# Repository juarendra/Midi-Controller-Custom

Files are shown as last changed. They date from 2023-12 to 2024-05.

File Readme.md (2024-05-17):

# MIDI CONTROLLER CUSTOM
This is MIDI CONTROLLER Combine with Macropad. Midi controller is for sending midi key to computer, ussually usage for remix musi on DAW Software. Macropad usage to sending macro key that register on QMK/VIA Firmware. there are 2 Microcontroller on this Project, All Microcontroller using Pro Micro and Connected with USB HUB inside Case. Macropad is installed QMK/VIA Firmware and Midi Controller is installed using Arduino Framework. For Button Midi Controller we use Arcade Button and there are 2 RGB LED on each Arcade Button and For Macropad we use MX Mechanical Switch with RGB on South Face.

For Case, we use 3D print that you can download on [this folder](https://github.com/juarendra/Midi-Controller-Custom/tree/main/HARDWARE/3DCASE). You can print this if you want to build this Project. For Firmware you can find in [this folder](https://github.com/juarendra/Midi-Controller-Custom/tree/main/Firmware).

## Spesification
- 2 x Atmega32u4 Pro Micro
- 1 x USB HUB minimal 2 Port
- 16 x Button Arcade with Transparant Frame + 2 RGB each Button
- 5 x Mechanical MX Switch and Keycaps + 1 RGB per key
- 5 x Hotswap Switch
- 1 x Encoder 
- 1 x USB Type B Female
- Macropad Compatible With VIA

for Connection from Pro Micro to all Button and RGB you can use Connector and skun, 

## Preview Hardware
<p align="center">
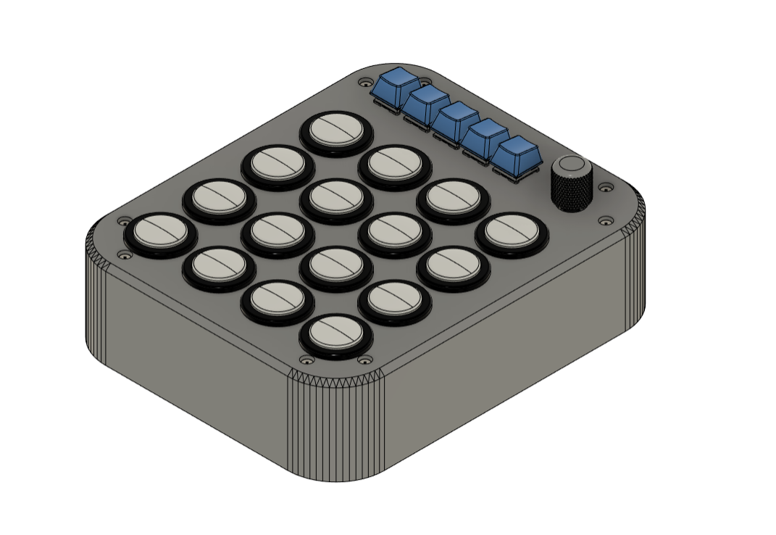
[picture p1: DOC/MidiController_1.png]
  
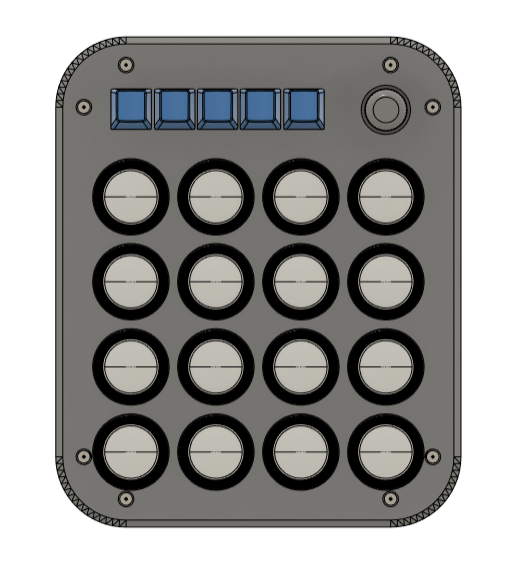
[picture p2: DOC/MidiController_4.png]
  
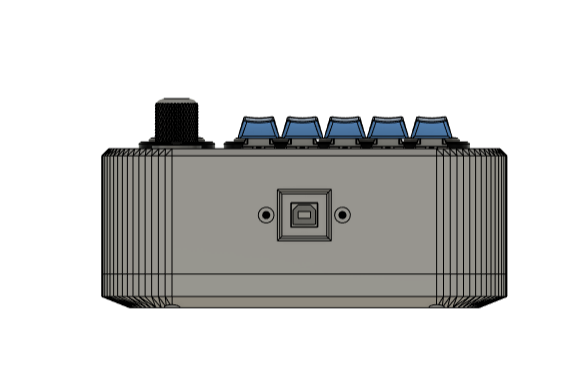
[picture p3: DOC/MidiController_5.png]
  
</p>

## Documentation Sensor V4
- [Dimension Sensor V4](https://github.com/juarendra/Midi-Controller-Custom/blob/main/HARDWARE/Dimension_MidiController.pdf)
- [JSON File For VIA](https://github.com/juarendra/Midi-Controller-Custom/blob/main/MidiController.json)

## BOM
| Item  | QTY |
| --- | --- |
| Arduino Pro Micor  | 2  |
| Arcade Button with transparant Frame 30mm | 16  |
| Switch Mechanical MX  | 5  |
| Keycaps Mechanical MX  | 5  |
| EC11 Rotary Encoder + Knob| 1  |
| Hotswap PCB Mechanical MX with LED RGB | 5  |
| RGB LED for Arcade Button | 32  |
| USB HUB minimal 2 Port | 1  |
| USB FEMALE type B | 1  |
| Wire and Skun | some  |

## FLASH FIRMWARE
- Flash QMK with QMK tollbox, the file you can find in [this link](https://github.com/juarendra/Midi-Controller-Custom/blob/main/Firmware/Macropad/25keys_cassette42_default.hex)
- Flash Midi Controller with arduino ,you need to install all library arduino, the file you can find in [this link](https://github.com/juarendra/Midi-Controller-Custom/blob/main/Firmware/MidiController/MidiController.ino)

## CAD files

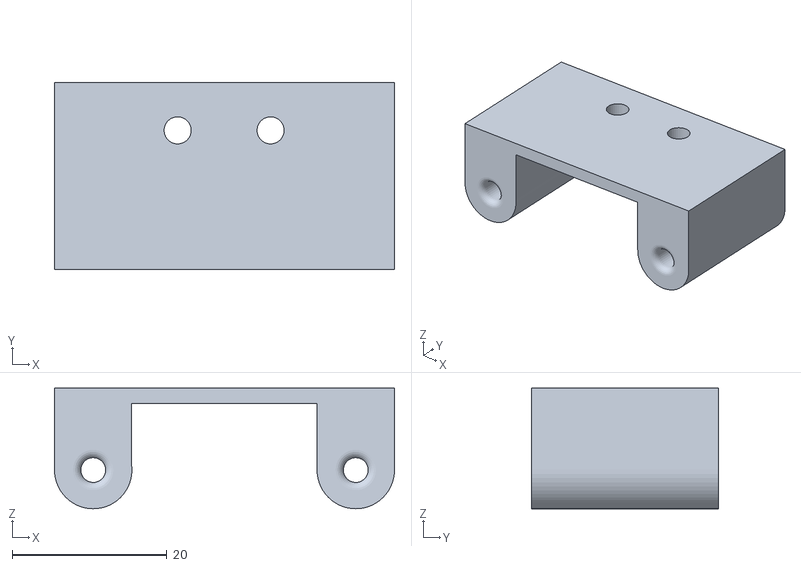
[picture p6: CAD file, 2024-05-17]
HARDWARE/3DCASE/USB_HOLDER_MidiController.stl
43.9 x 24.2 x 15.6

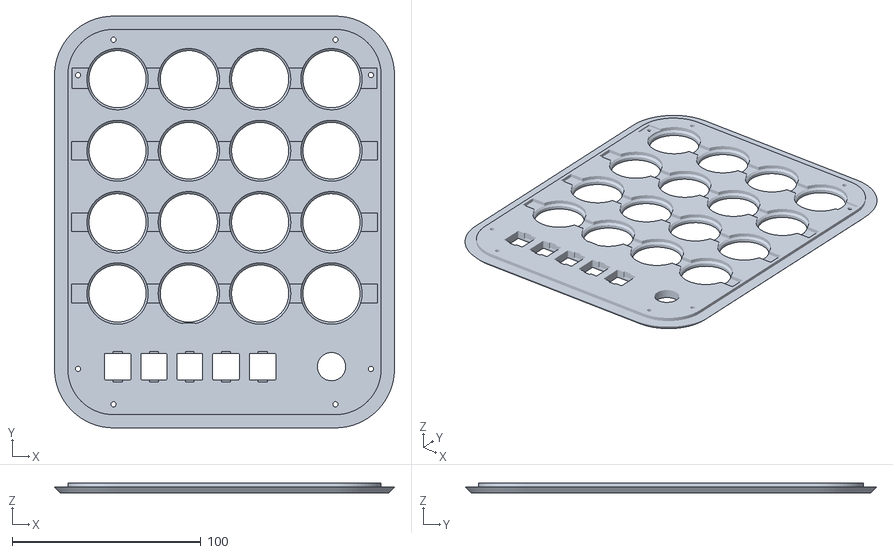
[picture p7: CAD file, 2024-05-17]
HARDWARE/3DCASE/TOP_MidiController.stl
180.0 x 218.0 x 5.27

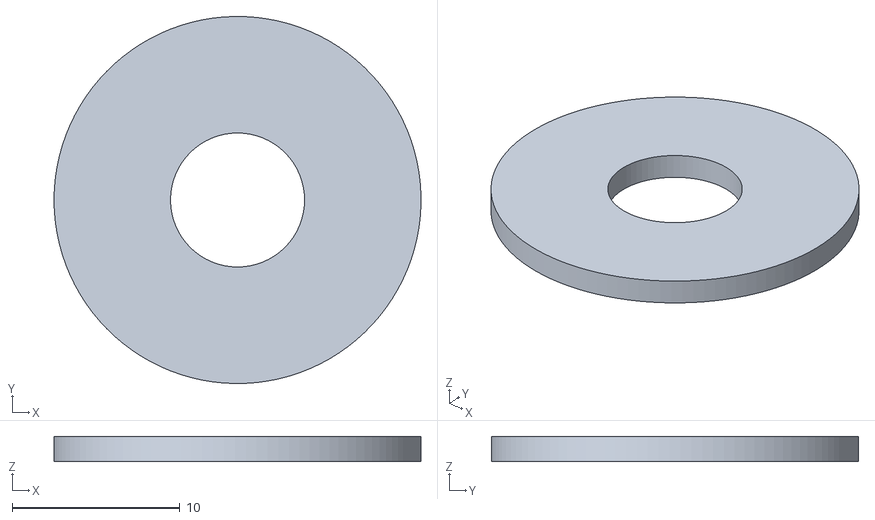
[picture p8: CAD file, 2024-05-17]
HARDWARE/3DCASE/ENCODER_BASE_MidiController.stl
21.9 x 21.9 x 1.50

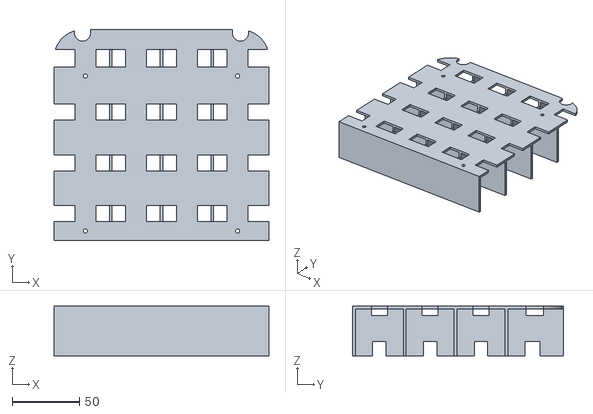
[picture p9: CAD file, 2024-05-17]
HARDWARE/3DCASE/LED_BRACKET_MidiController.stl
160.0 x 156.8 x 37.0

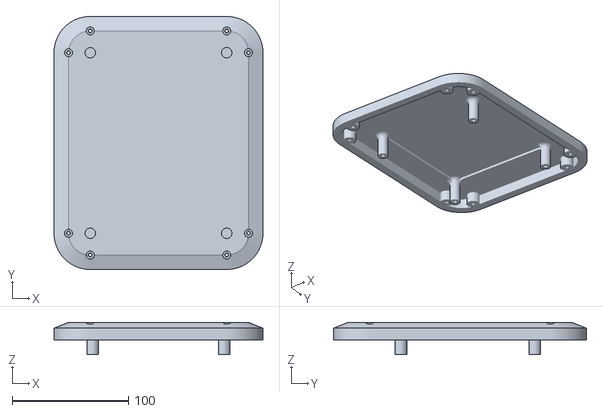
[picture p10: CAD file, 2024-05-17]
HARDWARE/3DCASE/BOTTOM_MidiController.stl
180.0 x 218.0 x 27.8

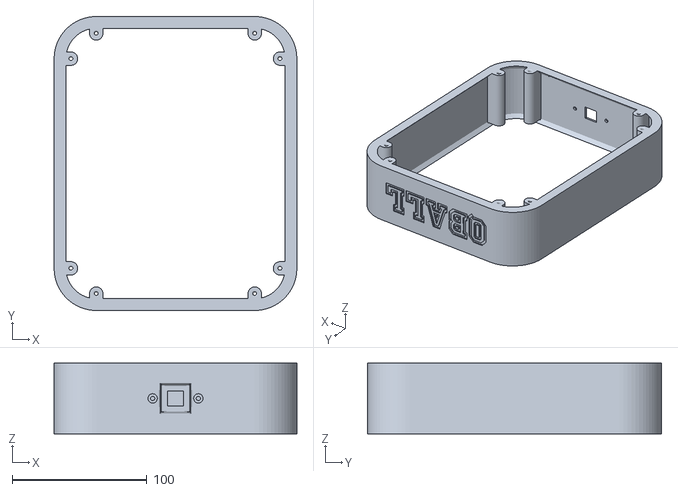
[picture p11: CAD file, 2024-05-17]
HARDWARE/3DCASE/MIDDLE_MidiController.stl
180.0 x 218.0 x 52.6

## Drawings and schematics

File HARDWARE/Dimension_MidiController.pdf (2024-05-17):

218 ¹⁸⁰ | 37.75 | 3.75 1.35 | 18.05 Ø7Ø25.5 | Ø34 | Ø9 Rubber Feet | Ø7 Baut M3 | Switch Knob Baut Arcade Button Ø7 Baut M3 USB Type B Female

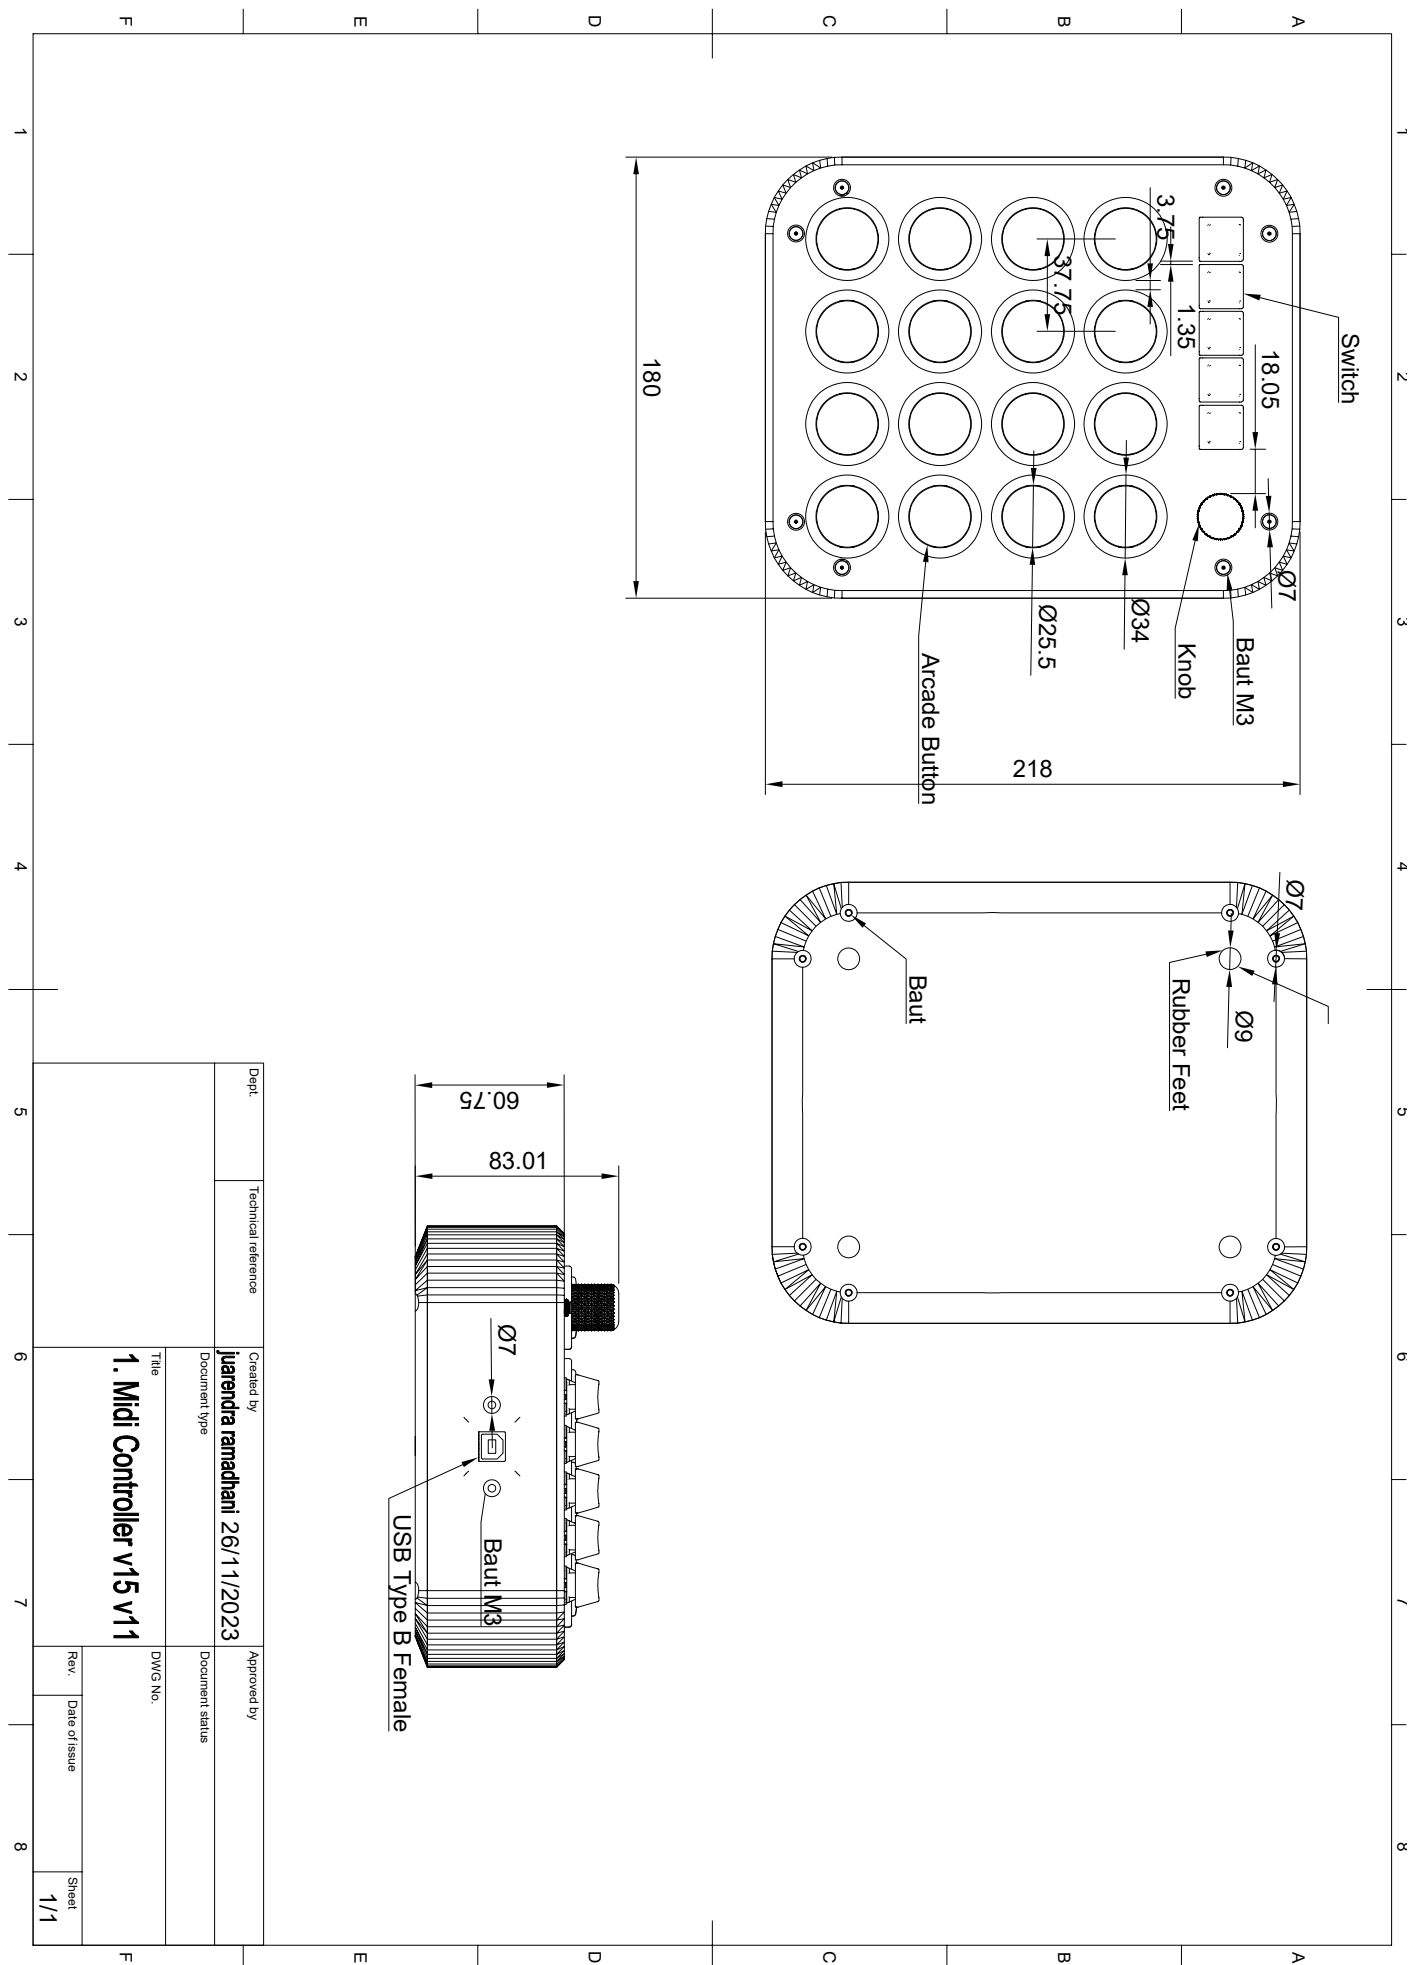
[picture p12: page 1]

1 A 2 3 4 5 6 7 8 1 2 3 4 5 6 7 8 FEDCB FEDCBA Dept. Technical reference Created by Approved by Title DWG No. Document type Document status Rev. Date of issue Sheet 26/11/2023 1/1

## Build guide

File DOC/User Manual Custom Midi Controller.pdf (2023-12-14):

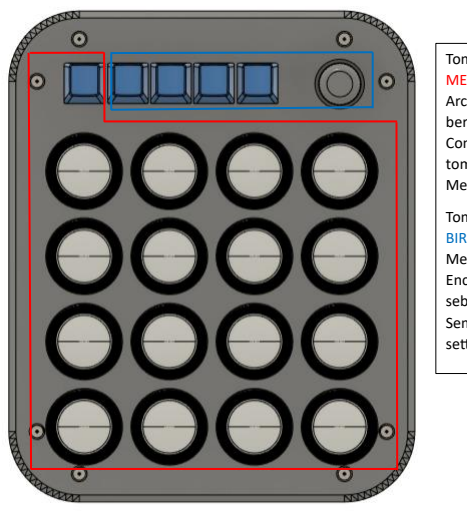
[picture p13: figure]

1. 16 Arcade Button
Berfungsi sebagai MIDI Controller yang mengirimkan signal note ke PC, Berikut merupakan maping dari note sesuai posisi button
48 | 49 | 50 | 51
44 | 45 | 46 | 47
40 | 41 | 42 | 43
36 | 37 | 38 | 39

Posisi ini menyesuaikan dengan posisi pads yang ada di aplikasi mpc beats

2. 1 Mechanical Button untuk menu
Berfungsi sebagai tombol untuk masuk ke menu yang ada di device. Ketika tombol ini di tekan dan ditahan maka akan memasuki mode menu., dan untuk memindahkan menu user perlu menekan tombol arcade sesuai dengan mapping menunya Tolong lihat video untuk lebih jelasnya.

Tombol didalam Kotak
MERAH : Terdiri dari 16
Arcade Button yang
berfungsi sebagai Midi
Controller dengan 1
tombol diatas untuk
Menu

Tombol didalam Kotak
BIRU : Terdiri dari 4
Mechanical Button dan 1
Encoder yang berfungsi
sebagai Macropad.
Semua key dapat di
setting dengan apps VIA

Berikut merupakan mapping menu sesuai posisi arcade button

Merubah warna pada Channel 3 ketika tombol ditekan | Merubah warna pada Channel 4 ketika tombol ditekan | Merubah warna pada Channel 5 ketika tombol ditekan | Merubah Brightness LED tombol
Merubah warna pada Channel 4 ketika tombol tidak ditekan | Merubah warna pada Channel 5 ketika tombol tidak ditekan | Merubah warna pada Channel 1 ketika tombol ditekan | Merubah warna pada Channel 2 ketika tombol ditekan
Midi Controller Channel 5 | Merubah warna pada Channel 1 ketika tombol tidak ditekan | Merubah warna pada Channel 2 ketika tombol tidak ditekan | Merubah warna pada Channel 3 ketika tombol tidak ditekan
Midi Controller Channel 1 | Midi Controller Channel 2 | Midi Controller Channel 3 | Midi Controller Channel 4

### 3. LED INDICATOR

Anda dapat mengetahui anda berada di menu apa dengan meilhat 5 LED yang ada di bawah 5 Mechanical Button. Berikut merupakan Contoh dari indicator lednya
1. Anda berada di Midi Controller Channel 1

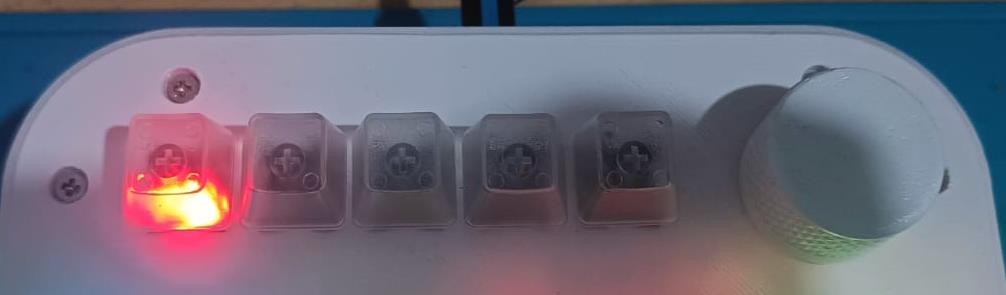
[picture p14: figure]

2. Anda berada di Midi Conntroller Channel 5
3. Anda berada di Setting warna Ketika tombol tidak ditekan

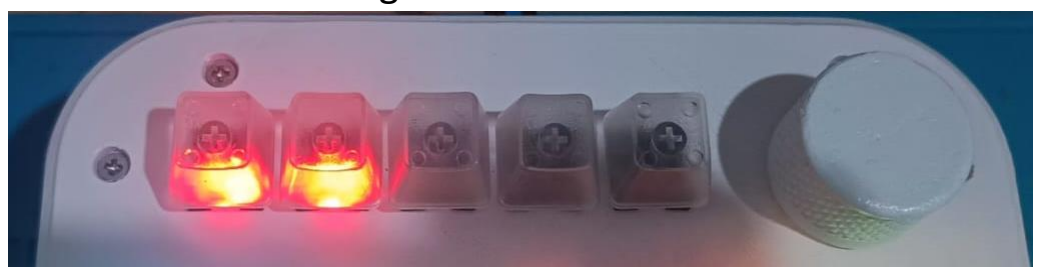
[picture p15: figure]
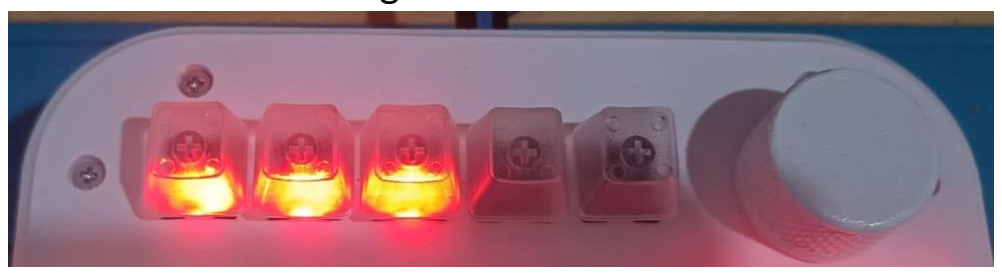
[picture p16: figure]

4. Anda berada di Setting warna Ketika tombol ditekan

5. Anda berada di Setting brightness warna

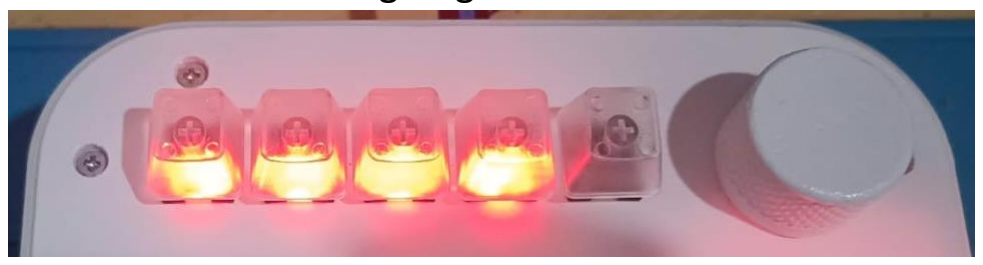
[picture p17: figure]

4. 4 Mechanical Button dan 1 Encoder KNOB .
Semua fungsi dari button dan encoder dapat di setting pada applikasi VIA. Berikut merupakan Langkah untuk melakukan setting
1. Colok dahulu Macropad pada PC
2. Buka Aplikasi VIA
3. Pada Tab Setting , aktifkan “Show Design Tab”
4. Buka Tan Design
5. Load file extension “json” di github yang di berikan
6. Buka tab Configure untuk melakukan setting
7. Jika masih muncul gambar searching, maka ulangi lagi load json file

Link Github: https://github.com/juarendra/Midi-Controller-Custom.git

### 5. Connect to Software DAW

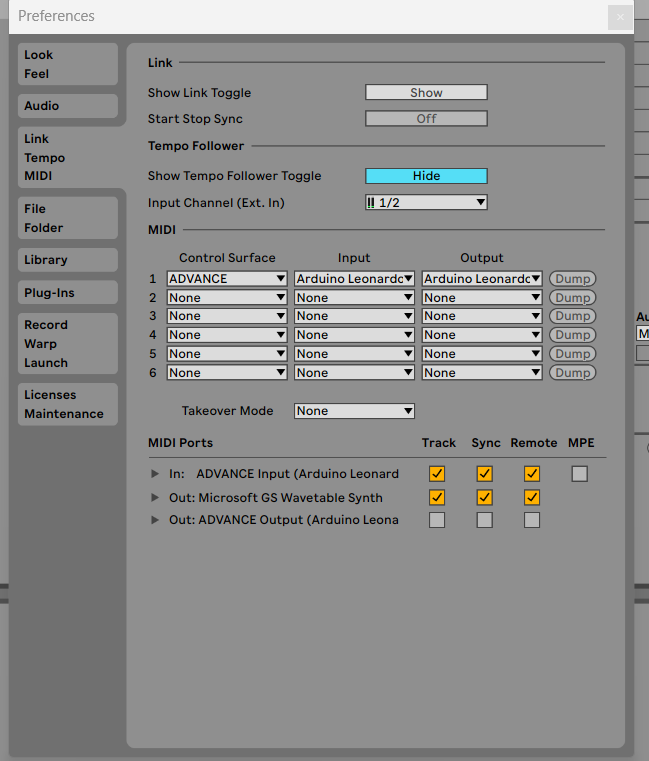
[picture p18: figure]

agar dapat Connect ke Software DAWnya anda perlu mengaktifkan Input MIDI Controller “Arduino Leonardo”

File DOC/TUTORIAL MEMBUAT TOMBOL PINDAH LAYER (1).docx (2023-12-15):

1. Buka App VIA Configurator

2. Masukan File JSON keymap yang ada di google drive

3. Hubungkan Macropad ke PC

4. Buka Tab Configure

5. Pada Tab Configure pilih Tab Layer

6. Tentukan 1 Tombol yang akan digunakan untuk perpindahan layer

7. Ketika baru pertama dihubungkan ke PC maka macropad otomatis berada pada layer 0,

8. Klick tombol tersebut dan ganti fungsi menjadi TG1(isi dari tab layer), ini artinya fungsi tombol tersebut adalah memidahkan layer sekarang ke layer 1

9. Pindah ke layer 1, lalu klick tombol tersebut lagi dan ganti fungsi menjadi TG2(isi dari tab layer), ini artinya fungsi tombol tersebut adalah memidahkan layer sekarang ke layer 2

10.Pindah ke layer 2, lalu klick tombol tersebut lagi dan ganti fungsi menjadi TG3(isi dari tab layer), ini artinya fungsi tombol tersebut adalah memidahkan layer sekarang ke layer 3

11. Pindah ke layer 3, lalu klick tombol tersebut lagi dan ganti fungsi menjadi TO1(isi dari tab layer), ini artinya fungsi tombol tersebut adalah memindahkan layer sekarang kembali lagi ke layer 0

12. Selesai

layer 0 ----> layer 1 ----> layer 2 ----> layer 3 ----> layer 0

TO1 TO2 TO3 TO0

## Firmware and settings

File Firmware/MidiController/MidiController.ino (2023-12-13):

/*
  Made by Gustavo Silveira, 2019.
  - This Sketch reads the Arduino's digital and analog ports and send midi notes and midi control change
  - It can use many multiplexers

  http://www.musiconerd.com
  http://www.youtube.com/musiconerd
  http://facebook.com/musiconerdmusiconerd
  http://instagram.com/musiconerd/
  http://www.gustavosilveira.net
  gustavosilveira@musiconerd.com

  If you are using for anything that's not for personal use don't forget to give credit.

  PS: Just change the value that has a comment like " //* "

*/

//////////////////////////////////////
// If using Fast Led
#include "EEvar.h"

#include "FastLED.h"

FASTLED_USING_NAMESPACE

#define DATA_PIN    8
//#define CLK_PIN   4
#define LED_TYPE    WS2812
#define COLOR_ORDER GRB
#define NUM_LEDS    37
#define NUM_LEDS_1    16
#define HUE_OFFSET 90
CRGB leds[NUM_LEDS];
byte ledIndex[NUM_LEDS_1] = {30, 28, 26, 24, 16, 18, 20, 22, 14, 12, 10, 8, 0, 2, 4, 6};
byte ledIndex_[NUM_LEDS_1] = {31, 29, 27, 25, 17, 19, 21, 23, 15, 13, 11, 9, 1, 3, 5, 7};



#define BRIGHTNESS          96
#define FRAMES_PER_SECOND  120

byte listCh1OffHue[16] = {10, 20, 30, 40, 50, 60, 70, 80, 90, 100, 110, 120, 130, 140, 150, 160};
byte listCh1OnHue[16] = {0, 0, 0, 0, 0, 0, 0, 0, 0, 0, 0, 0, 0, 0, 0, 0};

byte listCh2OffHue[16] = {50, 50, 50, 50, 50, 50, 50, 50, 50, 50, 50, 50, 50, 50, 50, 50};
byte listCh2OnHue[16] = {0, 0, 0, 0, 0, 0, 0, 0, 0, 0, 0, 0, 0, 0, 0, 0};

byte listCh3OffHue[16] = {100, 100, 100, 100, 100, 100, 100, 100, 100, 100, 100, 100, 100, 100, 100, 100};
byte listCh3OnHue[16] = {0, 0, 0, 0, 0, 0, 0, 0, 0, 0, 0, 0, 0, 0, 0, 0}; 

byte listCh4OffHue[16] = {125, 125, 125, 125, 125, 125, 125, 125, 125, 125, 125, 125, 125, 125, 125, 125};
byte listCh4OnHue[16] = {0, 0, 0, 0, 0, 0, 0, 0, 0, 0, 0, 0, 0, 0, 0, 0};

byte listCh5OffHue[16] = {215, 215, 215, 215, 215, 215, 215, 215, 215, 215, 215, 215, 215, 215, 215, 215};
byte listCh5OnHue[16] = {0, 0, 0, 0, 0, 0, 0, 0, 0, 0, 0, 0, 0, 0, 0, 0};

byte ch1Hue = 1;
byte maxHue = 240;
byte brightness = 240;


struct Config {
  byte listCh1OffHue[16];
  byte listCh1OnHue[16] ;

  byte listCh2OffHue[16] ;
  byte listCh2OnHue[16];

  byte listCh3OffHue[16];
  byte listCh3OnHue[16];

  byte listCh4OffHue[16] ;
  byte listCh4OnHue[16];

  byte listCh5OffHue[16] ;
  byte listCh5OnHue[16] ;
  byte brightness;
};

//////////////////////////////////////

/////////////////////////////////////////////
// Choosing your board
// Define your board, choose:
// "ATMEGA328" if using ATmega328 - Uno, Mega, Nano...
// "ATMEGA32U4" if using with ATmega32U4 - Micro, Pro Micro, Leonardo...
// "TEENSY" if using a Teensy board
// "DEBUG" if you just want to debug the code in the serial monitor
// you don't need to comment or uncomment any MIDI library below after you define your board

#define ATMEGA32U4 1//* put here the uC you are using, like in the lines above followed by "1", like "ATMEGA328 1", "DEBUG 1", etc.

/////////////////////////////////////////////
// Are you using a multiplexer?
#define USING_MUX 1 //* comment if not using a multiplexer, uncomment if using it.

/////////////////////////////////////////////
// Are you using encoders?
// #define USING_ENCODER 1 //* comment if not using encoders, uncomment if using it.

/////////////////////////////////////////////
// LIBRARIES
// -- Defines the MIDI library -- //

// if using with ATmega328 - Uno, Mega, Nano...
#ifdef ATMEGA328
#include <MIDI.h>
//MIDI_CREATE_DEFAULT_INSTANCE();

// if using with ATmega32U4 - Micro, Pro Micro, Leonardo...
#elif ATMEGA32U4
#include "MIDIUSB.h"

#endif
// ---- //

//////////////////////
// Add this lib if using a cd4067 multiplexer
#ifdef USING_MUX
#include <Multiplexer4067.h> // Multiplexer CD4067 library >> https://github.com/sumotoy/Multiplexer4067
#endif

//////////////////////
// Threads
#include <Thread.h> // Threads library >> https://github.com/ivanseidel/ArduinoThread
#include <ThreadController.h> // Same as above



///////////////////////////////////////////
// MULTIPLEXERS
#ifdef USING_MUX

#define N_MUX 1 //* number of multiplexers
//* Define s0, s1, s2, s3, and x pins
#define s0 7
#define s1 6
#define s2 5
#define s3 3
#define x1 A6 // analog pin of the first mux
// add more #define and the x number if you need

// Initializes the multiplexer
Multiplexer4067 mux[N_MUX] = {
  Multiplexer4067(s0, s1, s2, s3, x1) // The SIG pin where the multiplexer is connnected
  // ...
};

#endif



/////////////////////////////////////////////
// BUTTONS
const int N_BUTTONS = 16; //*  total numbers of buttons. Number of buttons in the Arduino + number of buttons on multiplexer 1 + number of buttons on multiplexer 2...
const int N_BUTTONS_ARDUINO = 0; //* number of buttons connected straight to the Arduino (in order)
const int BUTTON_ARDUINO_PIN[N_BUTTONS] = {}; //* pins of each button connected straight to the Arduino

const int CHANNEL_BUTTON_PIN = 14;

//#define USING_CUSTOM_NN 1 //* comment if not using CUSTOM NOTE NUMBERS (scales), uncomment if using it.
#ifdef USING_CUSTOM_NN
int BUTTON_NN[N_BUTTONS] = {36, 40, 44, 48, 37, 41, 45, 49, 38, 42, 46, 50, 39, 43, 47, 51, 52};

//* Add the NOTE NUMBER of each button/switch you want
#endif

//#define USING_BUTTON_CC_N 1 //* comment if not using BUTTON CC, uncomment if using it.
#ifdef USING_BUTTON_CC_N // if using button with CC
int BUTTON_CC_N[N_BUTTONS] = {12, 16}; //* Add the CC NUMBER of each button/switch you want
#endif

//#define USING_TOGGLE 1 //* comment if not using BUTTON TOGGLE mode, uncomment if using it.
// With toggle mode on, when you press the button once it sends a note on, when you press it again it sends a note off

#ifdef USING_MUX // Fill if you are using mux, otherwise just leave it
const int N_BUTTONS_PER_MUX[N_MUX] = {16}; //* number of buttons in each mux (in order)
const int BUTTON_MUX_PIN[N_MUX][16] = { //* pin of each button of each mux in order
{
15, 14, 13, 12, 8, 10, 9, 11, 7, 6, 5, 4, 0, 1, 2, 3
}, //* pins of the first mux
// ...
};
#endif

int buttonMuxThreshold = 300;

int buttonCState[N_BUTTONS] = {0};        // stores the button current value
int buttonPState[N_BUTTONS] = {0};        // stores the button previous value

//#define pin13 1 // uncomment if you are using pin 13 (pin with led), or comment the line if it is not
byte pin13index = 12; //* put the index of the pin 13 of the buttonPin[] array if you are using, if not, comment

// debounce
unsigned long lastDebounceTime[N_BUTTONS] = {0};  // the last time the output pin was toggled
unsigned long debounceDelay = 5;    //* the debounce time; increase if the output flickers

// velocity
byte velocity[N_BUTTONS] = {127};


/////////////////////////////////////////////

/////////////////////////////////////////////
// CHANNEL
byte MIDI_CH = 0; //* MIDI channel to be used
byte BUTTON_MIDI_CH = 0; //* MIDI channel to be used
byte NOTE = 36; //* Lowest NOTE to be used - if not using custom NOTE NUMBER
byte CC = 1; //* Lowest MIDI CC to be used - if not using custom CC NUMBER

boolean channelMenuOn = false;
byte midiChMenuColor = 200;

int changeColorOn[5]  = {1, 2, 3, 4, 5};
int changeColorOff[5]  = {1, 2, 3, 4, 5};
bool menuChangeColor = false;
int selectedChangeColor = 99;

/////////////////////////////////////////////
// THREADS
// This libs create a "fake" thread. This means you can make something happen every x milisseconds
// We can use that to read something in an interval, instead of reading it every single loop
// In this case we'll read the potentiometers in a thread, making the reading of the buttons faster
ThreadController cpu; //thread master, where the other threads will be added
Thread threadChannelMenu; // thread to control the pots

const EEstore<Config> eeStruct((Config())); //store without buffering
Config conf;

void setup() {

  // Baud Rate
  // use if using with ATmega328 (uno, mega, nano...)
  // 31250 for MIDI class compliant | 115200 for Hairless MIDI
  //Serial.begin(115200); //*


  
  eeStruct >> conf;
  //delay(5000);
  //Serial.println(conf.listCh5OffHue[0]);
  //conf.listCh5OffHue[0] = 20;
  //eeStruct << conf;
#ifdef DEBUG
Serial.println("Debug mode");
Serial.println();
#endif


  ////////////////////////////////////
  //FAST LED
  FastLED.addLeds<LED_TYPE, DATA_PIN, COLOR_ORDER>(leds, NUM_LEDS).setCorrection(TypicalLEDStrip);

  // set master brightness control
  FastLED.setBrightness(conf.brightness);

  setAllLeds(ch1Hue, 0);// set all leds at once with a hue (hue, randomness)
  leds[36 - BUTTON_MIDI_CH].setHue(midiChMenuColor + 60); // turn the specific channel light on


  FastLED.show();

  //////////////////////////////////////

  //////////////////////////////////////
  // Buttons
  // Initialize buttons with pull up resistors
  for (int i = 0; i < N_BUTTONS_ARDUINO; i++) {
    pinMode(BUTTON_ARDUINO_PIN[i], INPUT_PULLUP);
  }

  pinMode(CHANNEL_BUTTON_PIN, INPUT_PULLUP);

#ifdef pin13 // Initialize pin 13 as an input
pinMode(BUTTON_ARDUINO_PIN[pin13index], INPUT);
#endif


  // Multiplexers
#ifdef USING_MUX

  // Initialize the multiplexers
  for (int i = 0; i < N_MUX; i++) {
    mux[i].begin();
  }
  //* Set each X pin as input_pullup (avoid floating behavior)
  pinMode(x1, INPUT_PULLUP);

#endif


  threadChannelMenu.setInterval(40); // every how many millisiconds
  threadChannelMenu.onRun(channelMenu); // the function that will be added to the thread

  cpu.add(&threadChannelMenu); // add every thread here
  
  
}

void loop() {

  if (BUTTON_MIDI_CH < 5){
    MIDIread();
    buttons();
  }
  if (BUTTON_MIDI_CH >= 5){
    if (BUTTON_MIDI_CH == 15){
      changeBrignes();
    }
    else{
      buttonsChangeColor();
    }
  }

  cpu.run();
}

void changeBrignes(){
    for (int i = 0; i < N_BUTTONS_ARDUINO; i++) {
    buttonCState[i] = digitalRead(BUTTON_ARDUINO_PIN[i]);
  }
  // It will happen if you are using MUX
  int nButtonsPerMuxSum = N_BUTTONS_ARDUINO; // offsets the buttonCState at every mux reading

  // read the pins from every mux
  for (int j = 0; j < N_MUX; j++) {
    for (int i = 0; i < N_BUTTONS_PER_MUX[j]; i++) {
      buttonCState[i + nButtonsPerMuxSum] = mux[j].readChannel(BUTTON_MUX_PIN[j][i]);
      // Scale values to 0-1
      if (buttonCState[i + nButtonsPerMuxSum] > buttonMuxThreshold) {
        buttonCState[i + nButtonsPerMuxSum] = HIGH;
      }
      else {
        buttonCState[i + nButtonsPerMuxSum] = LOW;
      }
    }
    nButtonsPerMuxSum += N_BUTTONS_PER_MUX[j];
  }

  
for (int i = 0; i < N_BUTTONS; i++) { 
  if ((millis() - lastDebounceTime[i]) > debounceDelay) {
    if (buttonPState[i] != buttonCState[i]) {
      lastDebounceTime[i] = millis();
      if (buttonCState[i] == LOW) {
        if (i == 15){
          conf.brightness += 10;
          if (conf.brightness >= 254){
            conf.brightness = 0;
          }
          FastLED.setBrightness(conf.brightness);
          eeStruct << conf;
        }
                     
      }
       buttonPState[i] = buttonCState[i];
      }
    }
  }

}

void buttonsChangeColor(){
    // read pins from arduino
  for (int i = 0; i < N_BUTTONS_ARDUINO; i++) {
    buttonCState[i] = digitalRead(BUTTON_ARDUINO_PIN[i]);
  }
  // It will happen if you are using MUX
  int nButtonsPerMuxSum = N_BUTTONS_ARDUINO; // offsets the buttonCState at every mux reading

  // read the pins from every mux
  for (int j = 0; j < N_MUX; j++) {
    for (int i = 0; i < N_BUTTONS_PER_MUX[j]; i++) {
      buttonCState[i + nButtonsPerMuxSum] = mux[j].readChannel(BUTTON_MUX_PIN[j][i]);
      // Scale values to 0-1
      if (buttonCState[i + nButtonsPerMuxSum] > buttonMuxThreshold) {
        buttonCState[i + nButtonsPerMuxSum] = HIGH;
      }
      else {
        buttonCState[i + nButtonsPerMuxSum] = LOW;
      }
    }
    nButtonsPerMuxSum += N_BUTTONS_PER_MUX[j];
  }
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

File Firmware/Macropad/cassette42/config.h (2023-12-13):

/*
Copyright 2019 monksoffunk

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
You should have received a copy of the GNU General Public License
along with this program.  If not, see <http://www.gnu.org/licenses/>.
*/

#pragma once


/* key matrix size */
#define MATRIX_ROWS 1
#define MATRIX_COLS 5

#define DIRECT_PINS {{ B6, B2, B3, C6, B5}}

#define ENCODERS_PAD_A { B4 }
#define ENCODERS_PAD_B { D7 }
#define ENCODER_RESOLUTION 4

#define WS2812_DI_PIN E6 
#ifdef WS2812_DI_PIN
#    define RGBLED_NUM 4
#    define RGBLIGHT_HUE_STEP 8
#    define RGBLIGHT_SAT_STEP 8
#    define RGBLIGHT_VAL_STEP 8
#    define RGBLIGHT_LIMIT_VAL 255 /* The maximum brightness level */
#    define RGBLIGHT_SLEEP         /* If defined, the RGB lighting will be switched off when the host goes to sleep */
#    define RGBLIGHT_EFFECT_BREATHING
#    define RGBLIGHT_EFFECT_RAINBOW_MOOD
#    define RGBLIGHT_EFFECT_RAINBOW_SWIRL
#    define RGBLIGHT_EFFECT_SNAKE
#    define RGBLIGHT_EFFECT_KNIGHT
#    define RGBLIGHT_EFFECT_CHRISTMAS
#    define RGBLIGHT_EFFECT_STATIC_GRADIENT
#    define RGBLIGHT_EFFECT_RGB_TEST
#    define RGBLIGHT_EFFECT_ALTERNATING
#    define RGBLIGHT_EFFECT_TWINKLE
#endif

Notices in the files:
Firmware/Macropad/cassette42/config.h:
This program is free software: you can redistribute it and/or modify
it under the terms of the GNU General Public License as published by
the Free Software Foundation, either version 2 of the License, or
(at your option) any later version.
